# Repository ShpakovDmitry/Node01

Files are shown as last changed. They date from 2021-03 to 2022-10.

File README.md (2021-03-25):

# Node01
Node01 is wireless mesh node. This node is the basis of backbone network.

###### Network example:
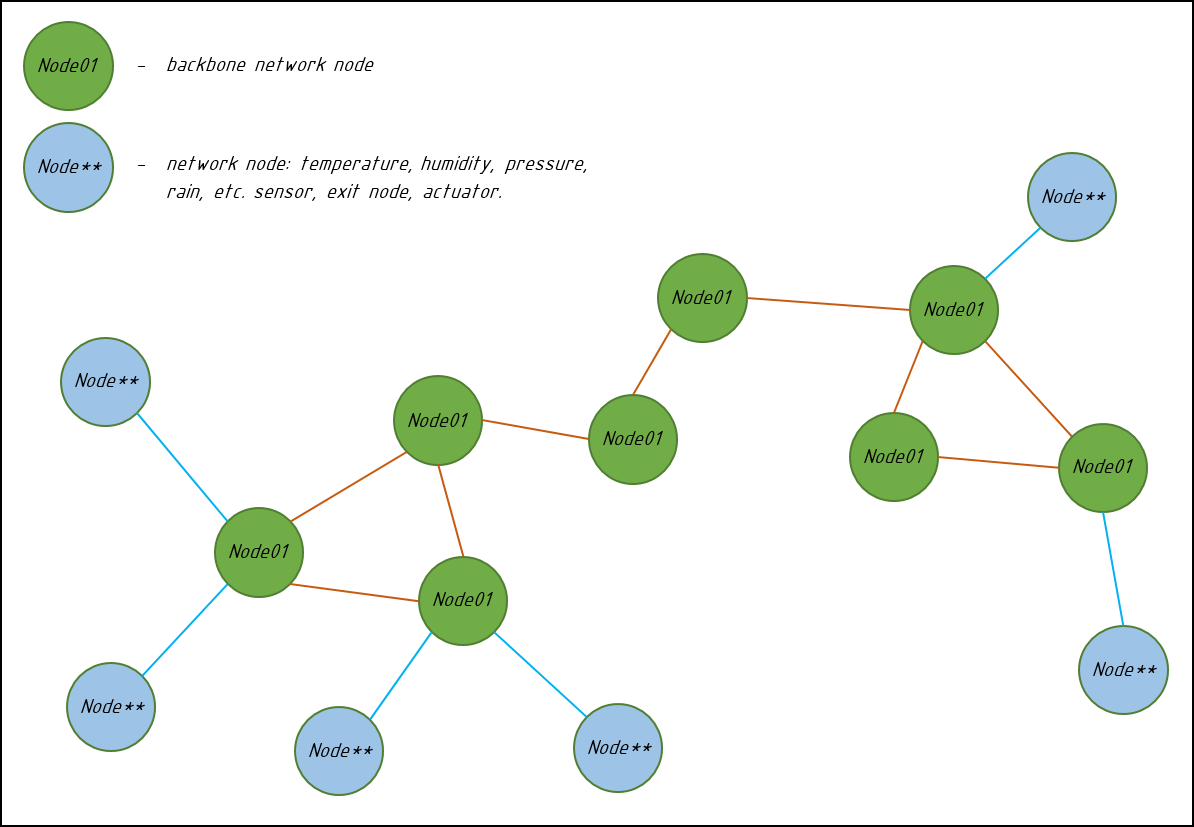
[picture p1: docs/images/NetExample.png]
netEample


###### Node01 block scheme:
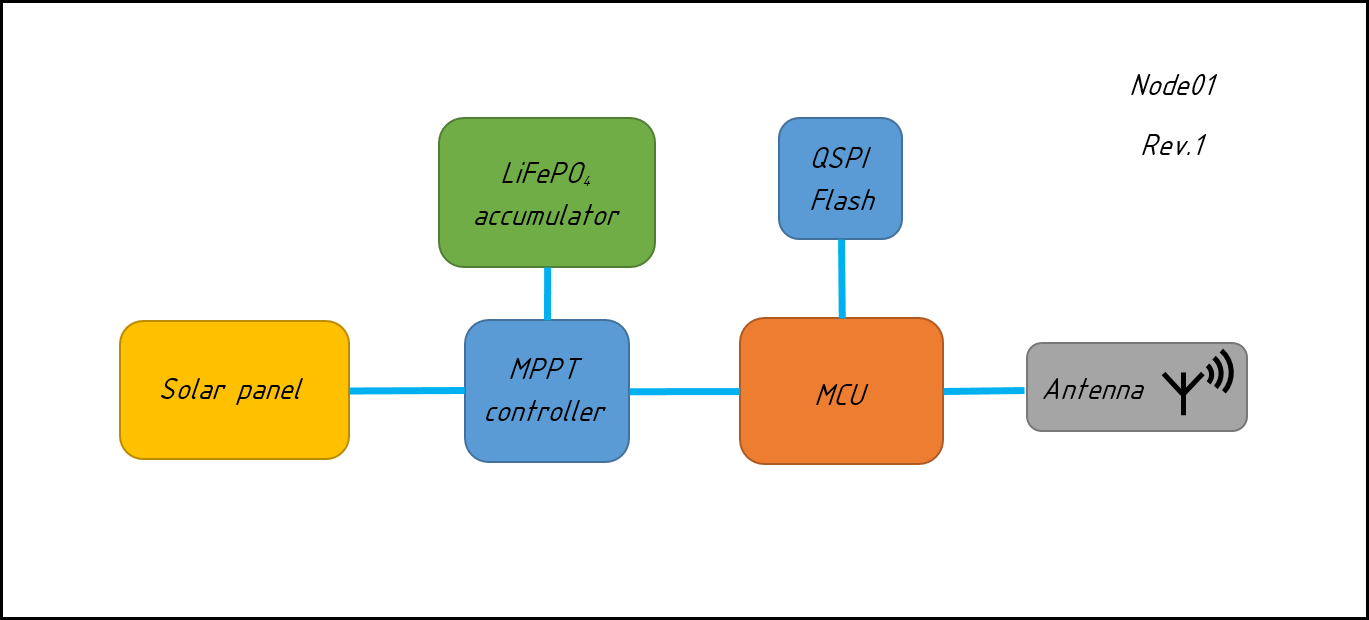
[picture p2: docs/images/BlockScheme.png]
BlockScheme


### Requirements
**Hardware**
* Based on Nordic Semiconductor IC (ex. nRF52840, ...)
* Continuous RF operation RX/TX
* Mostly static geo-position
* Autonomous power supply with a backup battery source
* Energy storage is supercap or LiFePO4(operates at low temperatures)
* Power connector for external solar panel or another energy source if available
* Switchable antenna to on-board or external SMA connector
* -40...+80 C deg outdoor temperature of operation
* minimum IP-63 protection
* Self monitor feature (integral temperature, battery lifetime monitoring)
* Flash storage IC
* UART interface
* 

**Software**
* Proprietary 2.4GHz protocol
* Operates as a router/switch
* Event based cooperative scheduler(in plans)
* Event-driven active object paradigm
* Or some of RTOS
* Modular hardware dependant part i.e. change in base board does not change
logic
of operation. Hardware are accessed throught API.
* C++ mixed with C and ASM for performance critical code sections(if possible)
* FOTA update
* Communication security: TBD !
* Minimal maintenance concept
* Self test feature
* Delay reliable communication
*

###### Power consumption analysis
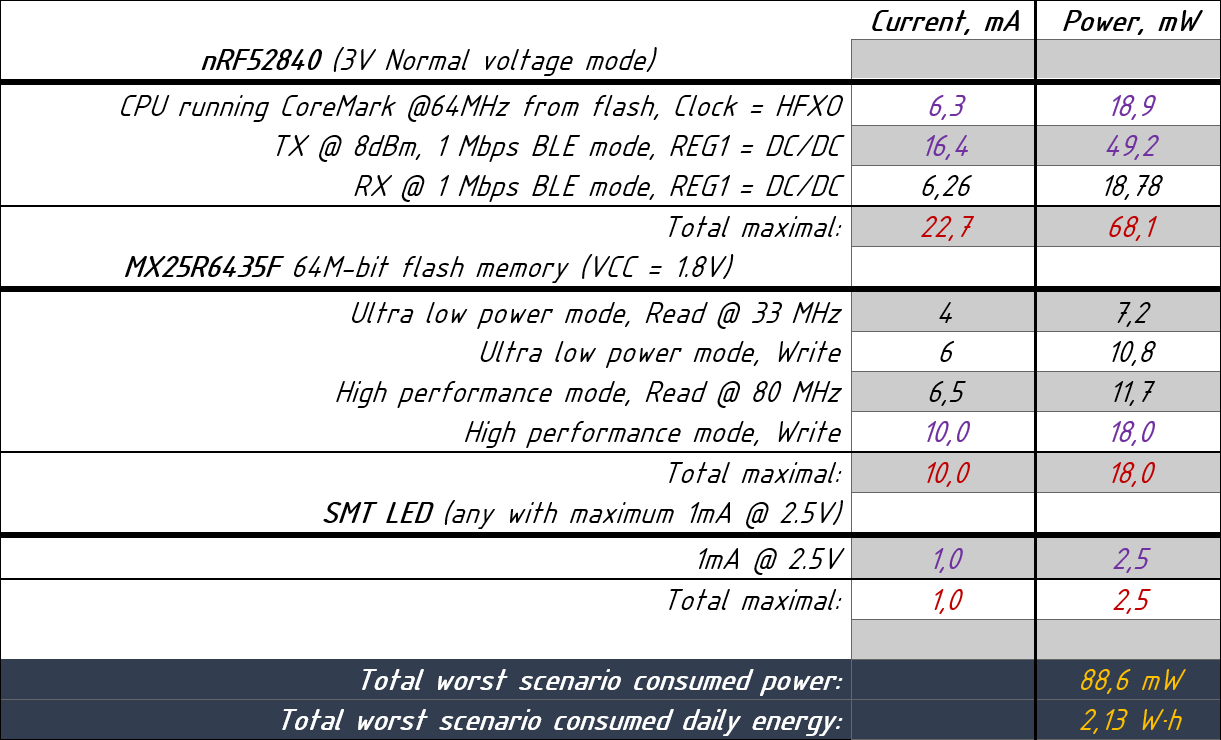
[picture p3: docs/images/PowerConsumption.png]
PowerConsumption

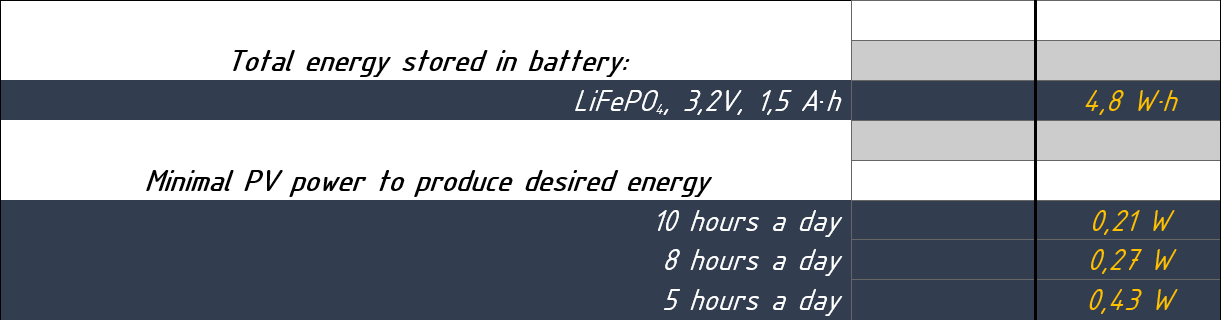
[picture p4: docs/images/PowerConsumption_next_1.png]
EnergyStored


###  Progress checklist
**Documentation**
- [x] Technical specifications added.
- [x] Power consumption analysis.
- [ ] Description.
- [ ] Hardware.
- [ ] Source.

**Hardware**
- [ ] Schematics designed.
- [ ] Simulations.
- [ ] PCB routed.
- [ ] Simulations.
- [ ] Rev. 1 manufactured.
- [ ] Rev. 1 tested.
- [ ] Changes to Rev. 1 made.
- [ ] Rev. 2 manufactured.
- [ ] Rev. 2 tested.
- [ ] Test passed.

**Software**
- [ ] Coding style guidleines added.
- [ ] Project guidlines added.
- [ ] Project organized.
- [ ] Build system created.
- [ ] Unit test system created.
- [ ] ... TBA
- [ ] MVP.
- [ ] Release of v.1.0.0

ProjectLogs

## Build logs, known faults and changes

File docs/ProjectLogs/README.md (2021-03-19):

# Project logs
> The purpose of this is to write decisions and changes made to project.

Put:
* current commit hash i.e. at the begining of discussion.
* Date.
* Reporter name.
* Problem description.

---

## Table of contents

1. [Power consumption analysis](#power-consumption-analysis)
1. [MPPT controller](#mppt-controller)
1. [Backup battery](#backup-battery)
1. [Energy sources](#energy-sources)
1. [Energy accumulator](#energy-accumulator)

##### Power consumption analysis.
```
       Number: 1
Project state: 4f51f26244daa80a04ce5664aafaebc53eb92157
         Date: 18/03/2021
     Reporter: Dmitry
      Problem: Too high power consumption, too high energy storage, too high
               PV power.
```
According to current setup,

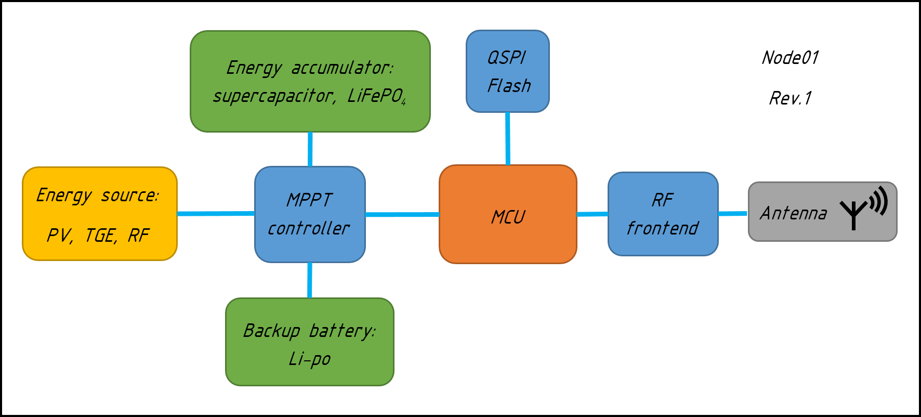
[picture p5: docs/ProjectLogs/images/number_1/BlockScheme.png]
BlockScheme


power consumption analysis showed that worst
scenario daily consumed energy is `10.6 W*h`. Excluding system efficiency out
of calculation. Energy transfer - store - transfer efficiency could be ~80 %.

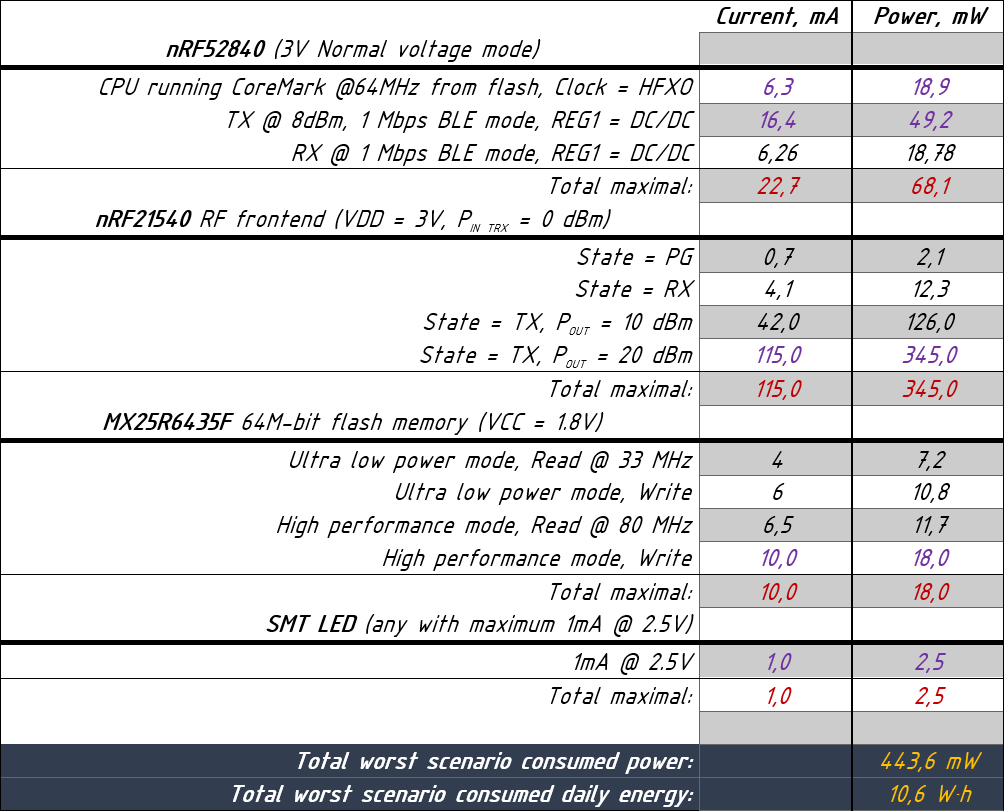
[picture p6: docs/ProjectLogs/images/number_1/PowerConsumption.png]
PowerConsumption


Which leads to LiFePO4 battery with `3.3 A*h` minimal capacity. Thus, to fully
charge up this battery in most optimistic scenario, 10 hour sunny day, `1.06 W`
PV panel is needed. Or `2.12 W` PV panel in 5 hour sunny day.

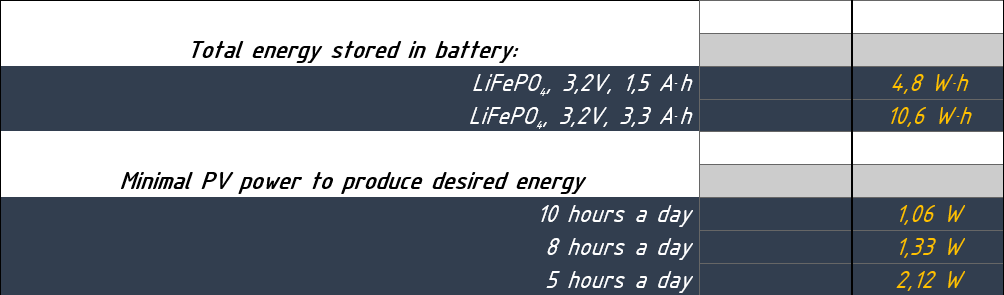
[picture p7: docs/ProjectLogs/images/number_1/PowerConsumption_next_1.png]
EnergyStored


```
Solution: Exclude RF frontend. This will lower worst scenario power consumption
          by `345 mW`.
```

##### MPPT controller.
```
       Number: 2
Project state: 83ee388a7370879099274ff98fa68130488713f3
         Date: 18/03/2021
     Reporter: Dmitry
      Problem: Is AEM10941 MPPT controller suitable for current setup?
```
If we assume that there is minimum 5 hour of sun a day then `0.43 W` PV is
needed. If accept that energy converter is 80% efficient, then we need
`0.54 W` PV. According to `AEM10941` [datasheet](../datasheet/DS_AEM10941.pdf)
maximal harvesting power is `550 mW` at `5 V` input voltage.

```
Solution: AEM10941 is suitable for this setup.
```

###### Backup battery.
```
       Number: 3
Project state: bc0d5789db9773c0944a8ec2a8e91152fdf4df60
         Date: 19/03/2021
     Reporter: Dmitry
      Problem: Is backup battery actually required?
```

According to current setup,

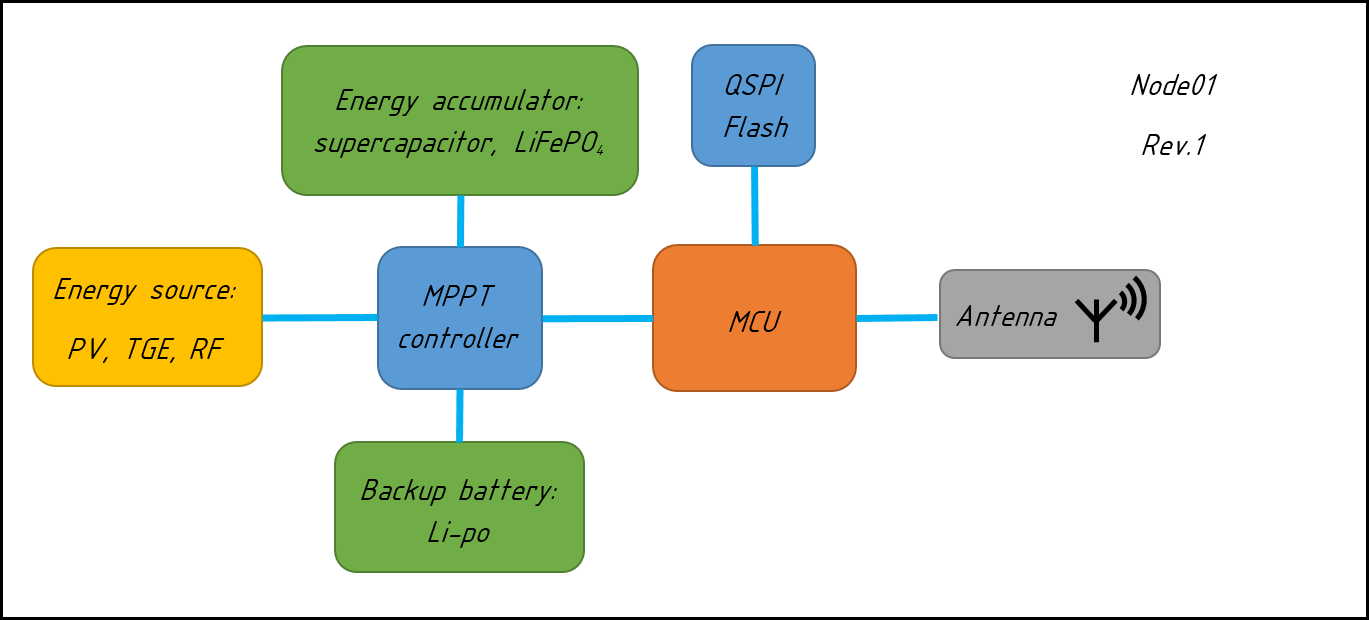
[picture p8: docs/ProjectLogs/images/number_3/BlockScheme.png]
BlockScheme


High capacity Li-po backup battery is used for periods of time when there is a
lack of harvested energy. This high capacity battery is precharged at install
in to device, and is not being charged during energy harvesting. Because if it
would be charged, then there is no meaning of two batteries, we could simply
increase capacity of rechargable one. Also use of this battery means that there
will be time when this battery should be replaced with charged one in order to
device successfully operates, as it will rely on existance of such backup
battery. So, using this battery means that we should track stored energy in
this battery and replace when it is empty. This leads to additional regular
maintenance of end device. This is in a contradiction with
_minimal maintenance concept_ described in device requirements.
```
Solution: exclude backup Li-po battery from design.
```

###### Energy sources.
```
       Number: 4
Project state: 1ef03a4303f460e012a083986df158970c159b4b
         Date: 19/03/2021
     Reporter: Dmitry
      Problem: What kind of energy sources actually will fit to the design?
```

According to current setup,

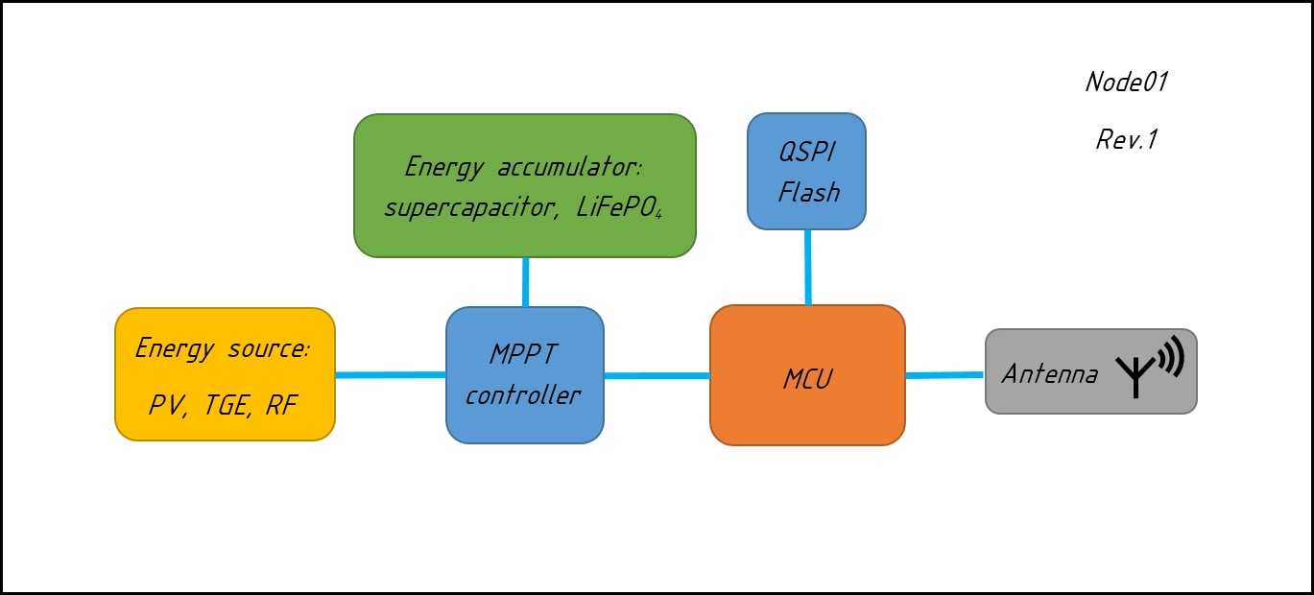
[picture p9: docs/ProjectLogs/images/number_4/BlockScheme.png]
BlockScheme


Energy sources used are photovoltaics(PV), thermo-electric generator(TEG),
radio-frequency energy(RF). Here we assume low cost, small size device is
desired.

| Energy source | Pros | Cons |
|:---:|:---:|:---:|
| RF | 24/7 operation | need nearby source, size  |
| TEG | 24/7 operation | good cooling system, size |
| PV | cheap, scalability | sunlight required, |

RF energy source will increase size of the device, also it will suffer
from RF energy source. TEG requires good cooling system and so will increase
size of the device. PV will increase size of the device, will operate only when
sunlight exists. Best candidate for this setup is PV as is cheap, easy scalable.
```
Solution: exlude RF, TEG energy sources variant from design. Leave only PV.
```

###### Energy accumulator.
```
       Number: 5
Project state: 4d961711aa97c4df6a963df5bf95f50167170b24
         Date: 19/03/2021
     Reporter: Dmitry
      Problem: What kind of energy accumulator will fit the best to the design?
```

Two candidates for current design:

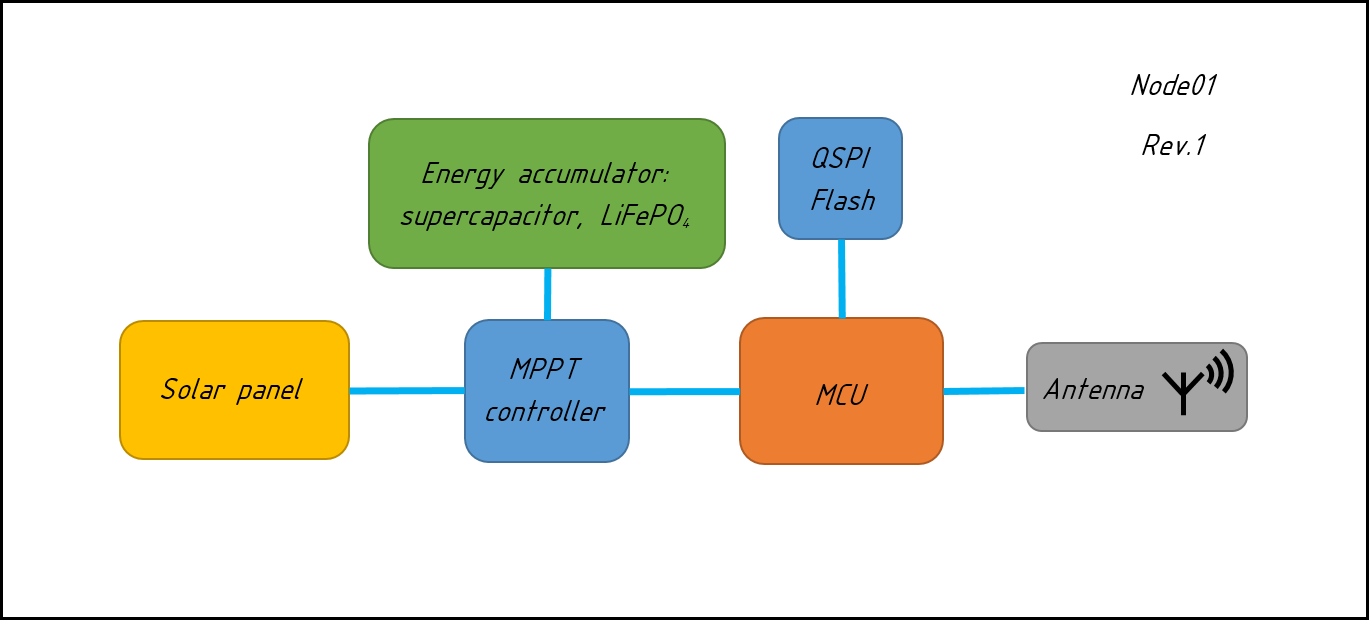
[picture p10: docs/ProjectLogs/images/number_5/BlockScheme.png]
BlockScheme


are supercapacitor and LiFePO4 battery.

| Energy accumulator | supercapacitor | LiFePO4 |
|:---:|:---:|:---:|
| Temp. range, C | -40...+125 | -40...+85 |
| Recharge cycles | 100k...1000k | 2k...10k |
| Specific en., Wh/kg| 1,5...3,9 | 90...160 |
| Specific pow., W/g | 2...10 | 0.3...1.5 |
| Self-discharge | weeks | months |
| Efficiency, % | 95 | 90 |
| Working life, y | 5...10 | 3...5 |

Both accumulators can be used in desired temperature range. LiFePO4 batteries
are with extended operation temperature range compared with Li-ion batteries.
However supercapacitors have higher recharge cycle amount, which means lower
maintenance. Looking at specific energy of accumulator here LiFePO4 battery is
out of concurence. This however means smaller device size. But supercapacitors
have higher specific power. But this criteria is not so meaningfuls as device
it self is low power. LiFePO4 self-discharge parameter is definitelly a win,
because any energy leakage means higher battery capacity or higher PV power.
Efficienty of both are comparable. And five years working life is acceptable.
So, for current design will stay at LiFePO4 batteries.
```
Solution: Use LIFePO4 battery.
```

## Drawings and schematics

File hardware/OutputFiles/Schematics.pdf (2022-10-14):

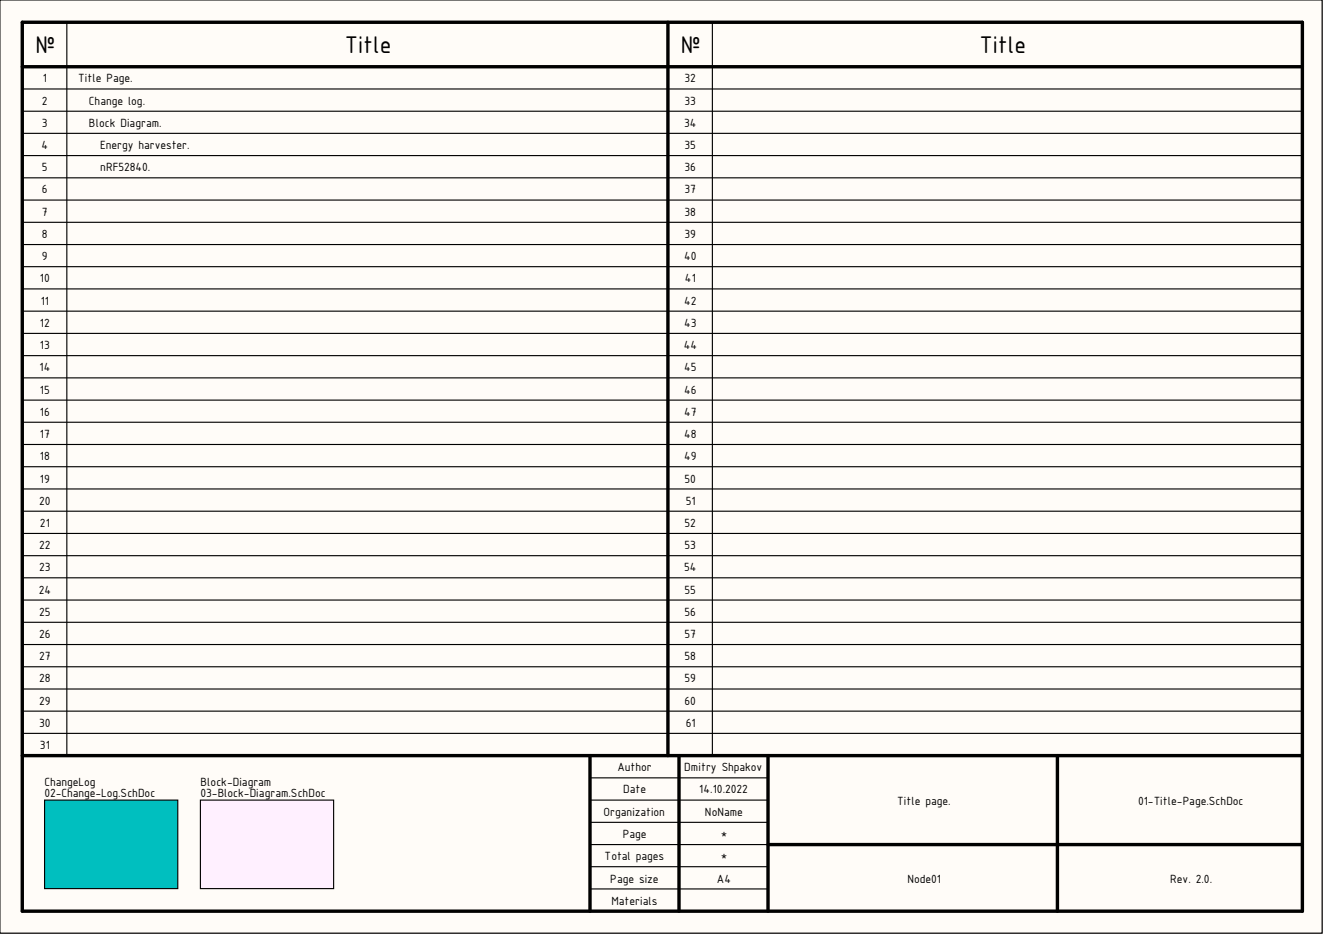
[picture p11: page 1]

№ | Title | № | Title

1 | Title Page. | 32

2 | Change log. | 33

3 | Block Diagram. | 34

4 | Energy harvester. | 35

5 | nRF52840. | 36

ChangeLog Block-Diagram 02-Change-Log.SchDoc 03-Block-Diagram.SchDoc | Author | Dmitry Shpakov | Title page. | 01-Title-Page.SchDoc

Date | 14.10.2022

Organization | NoName

Page | *

Total pages | * | Node01 | Rev. 2.0.

Page size | A4

Materials

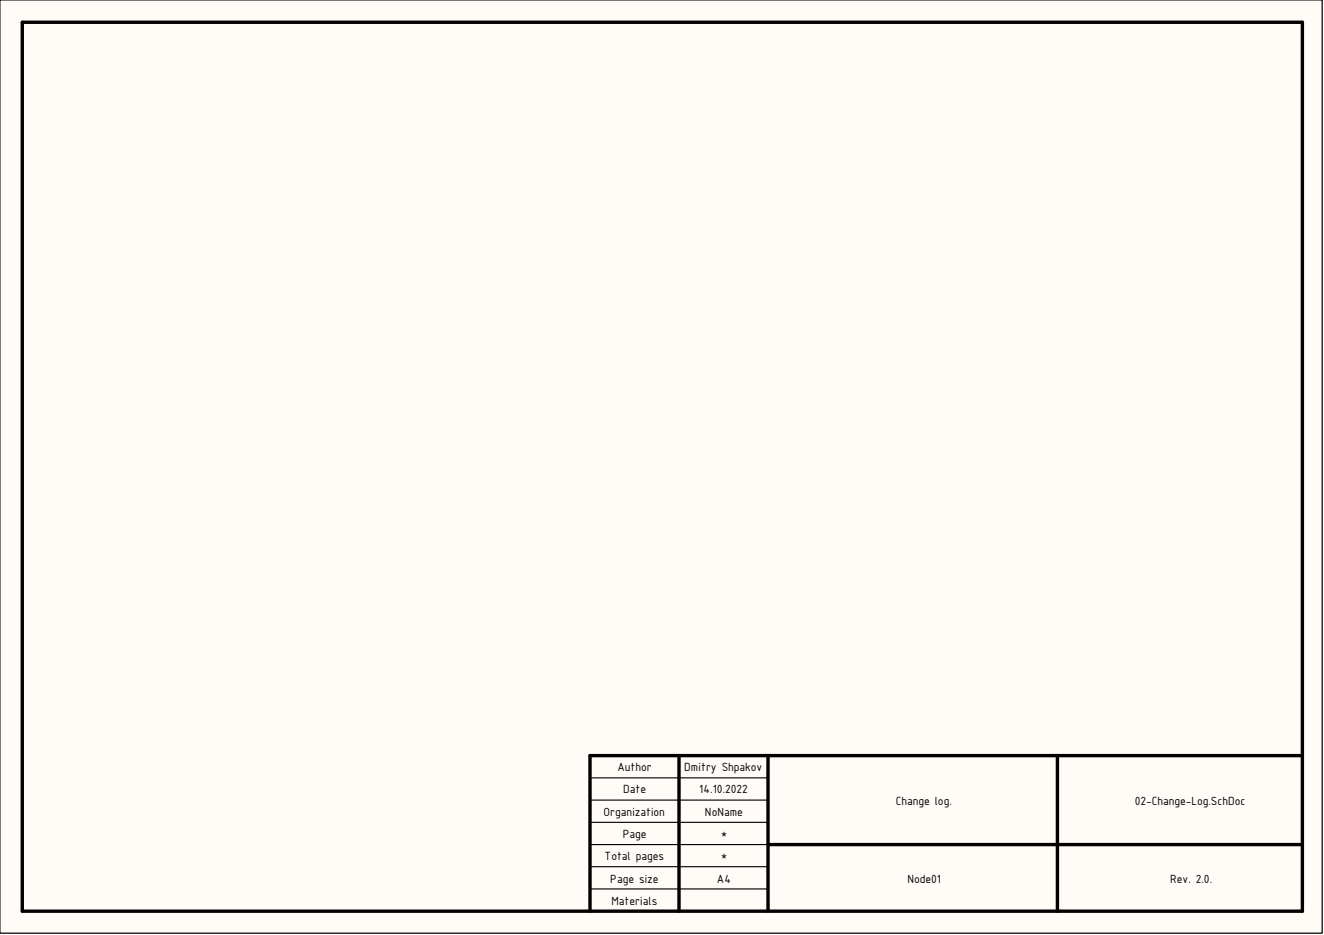
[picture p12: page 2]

Author | Dmitry Shpakov | Change log. | 02-Change-Log.SchDoc

Date | 14.10.2022

Organization | NoName

Page | *

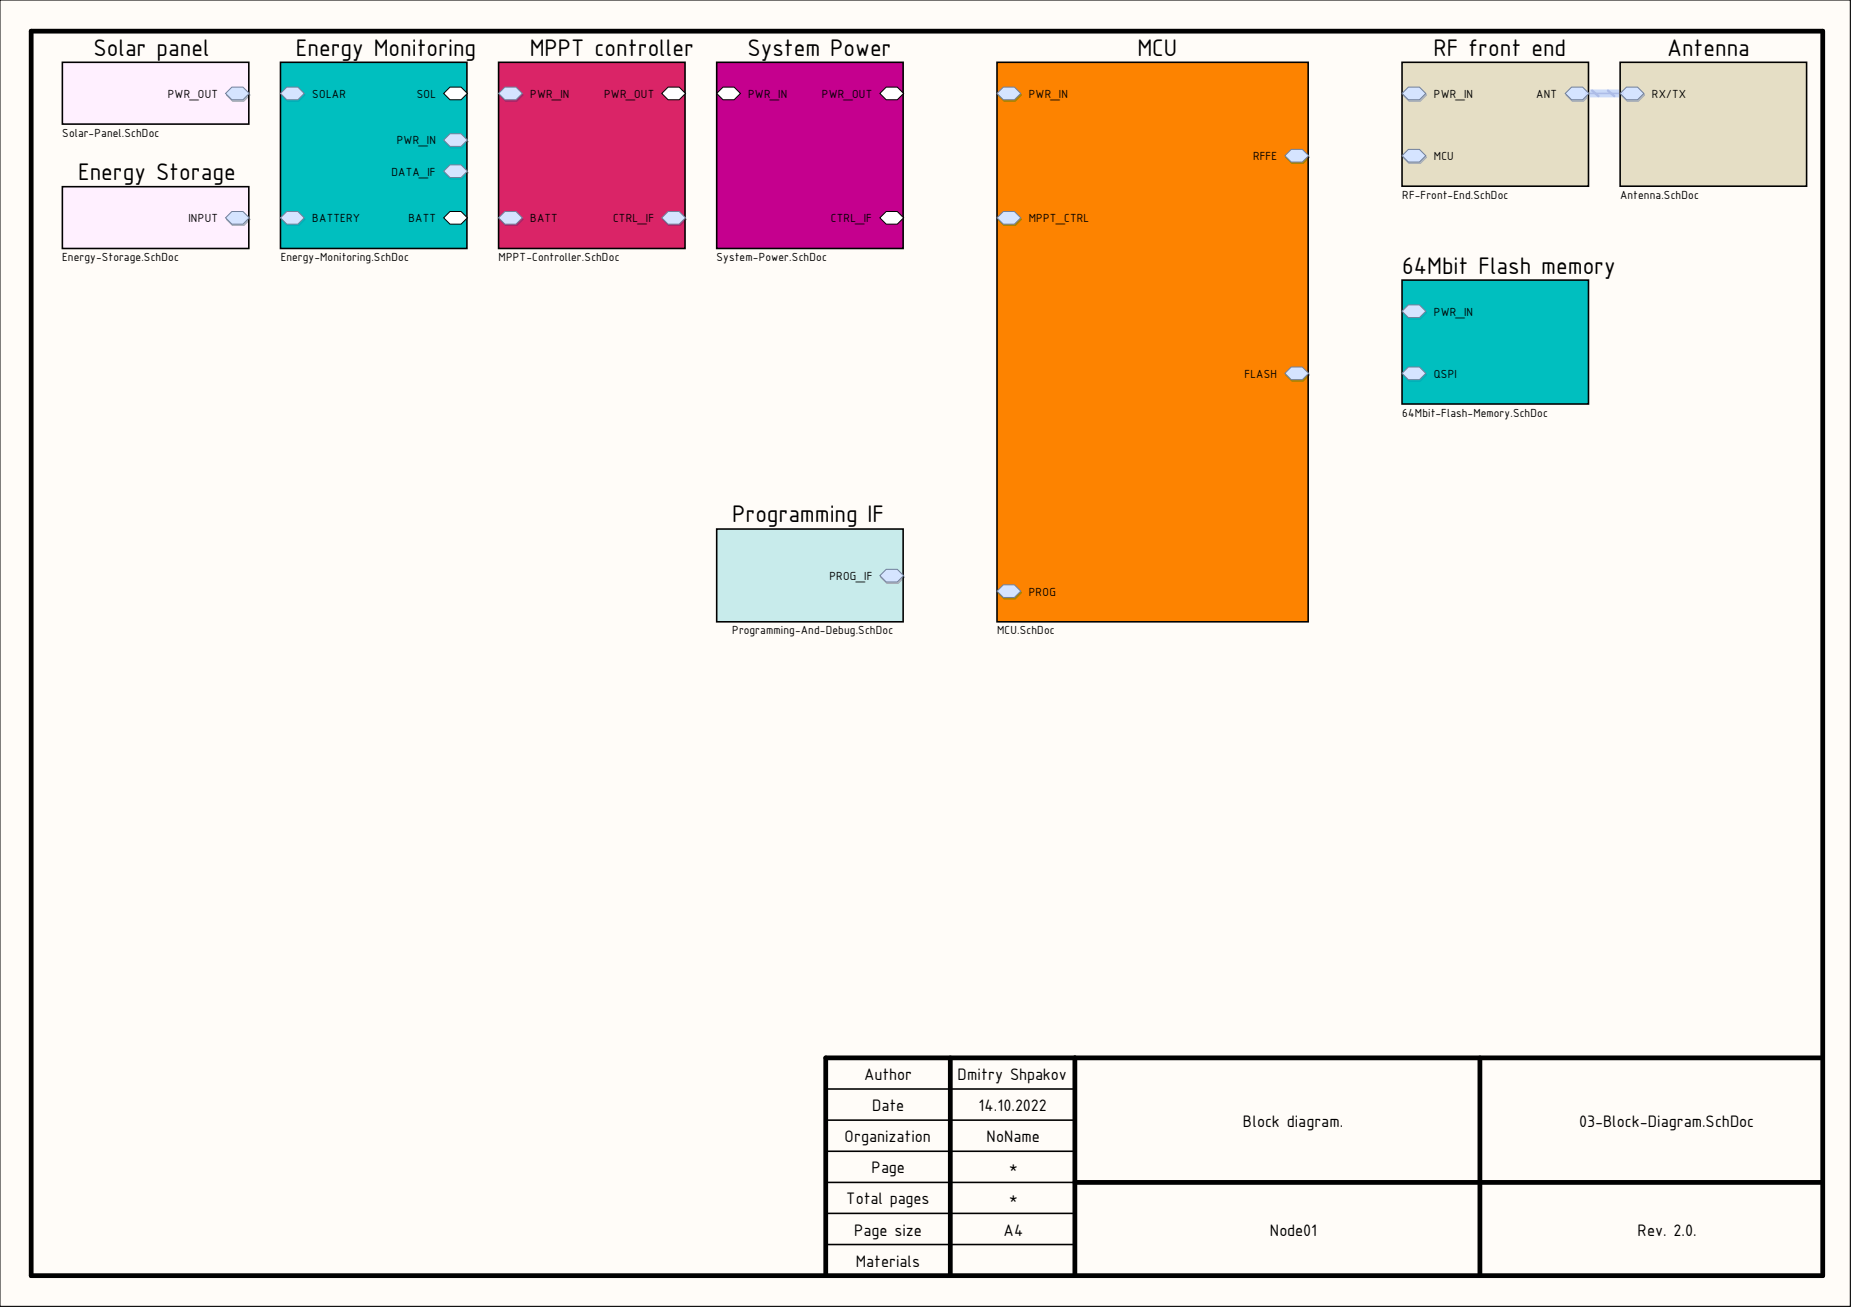
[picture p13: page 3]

RF-Front-End.SchDoc

Programming-And-Debug.SchDoc

Author | Dmitry Shpakov | Block diagram. | 03-Block-Diagram.SchDoc

Date | 14.10.2022

Organization | NoName

Page | *

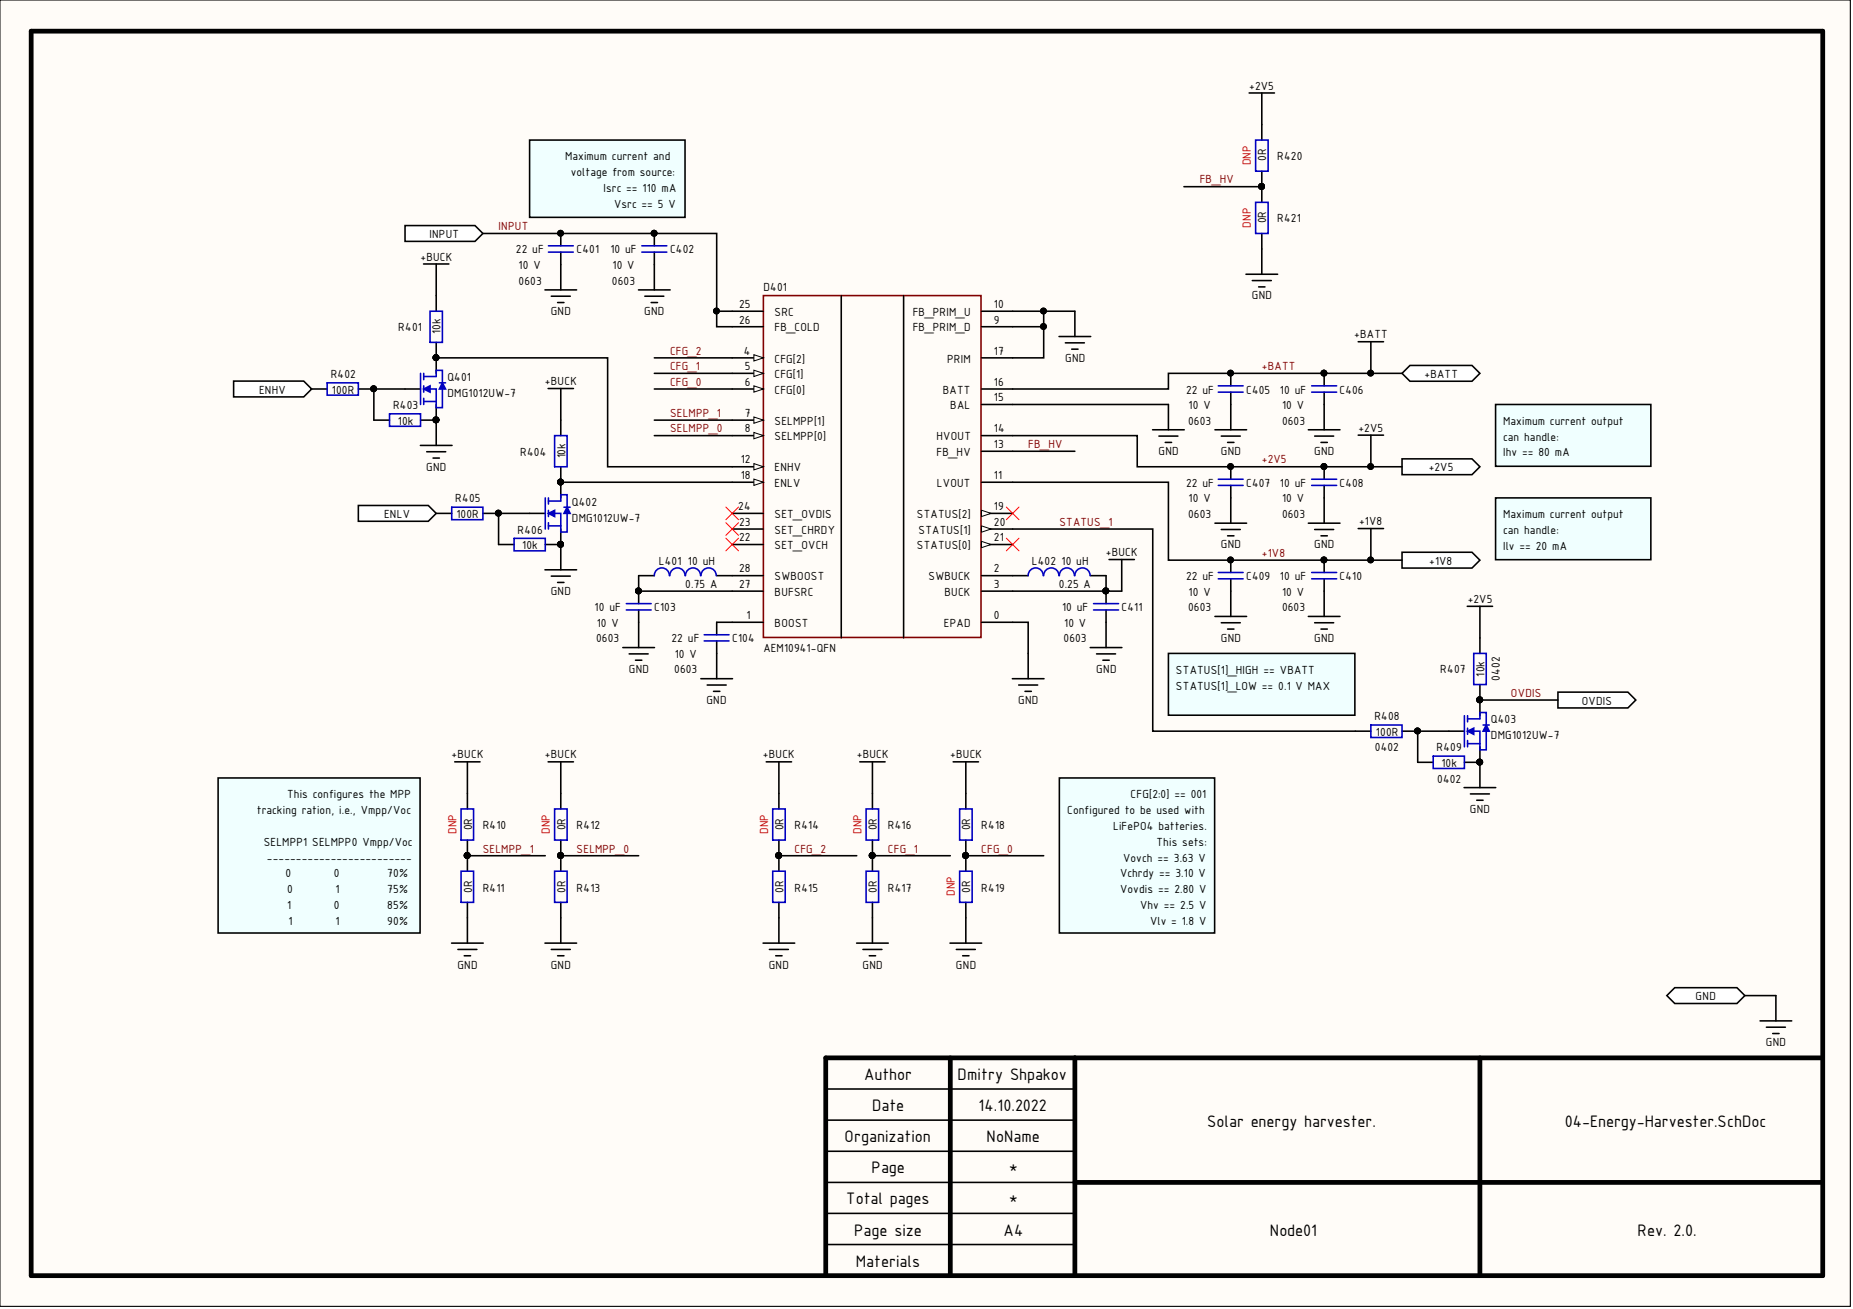
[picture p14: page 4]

This configures the MPP
tracking ration, i.e., Vmpp/Voc

Configured to be used with

Author | Dmitry Shpakov | Solar energy harvester. | 04-Energy-Harvester.SchDoc

Date | 14.10.2022

Organization | NoName

Page | *

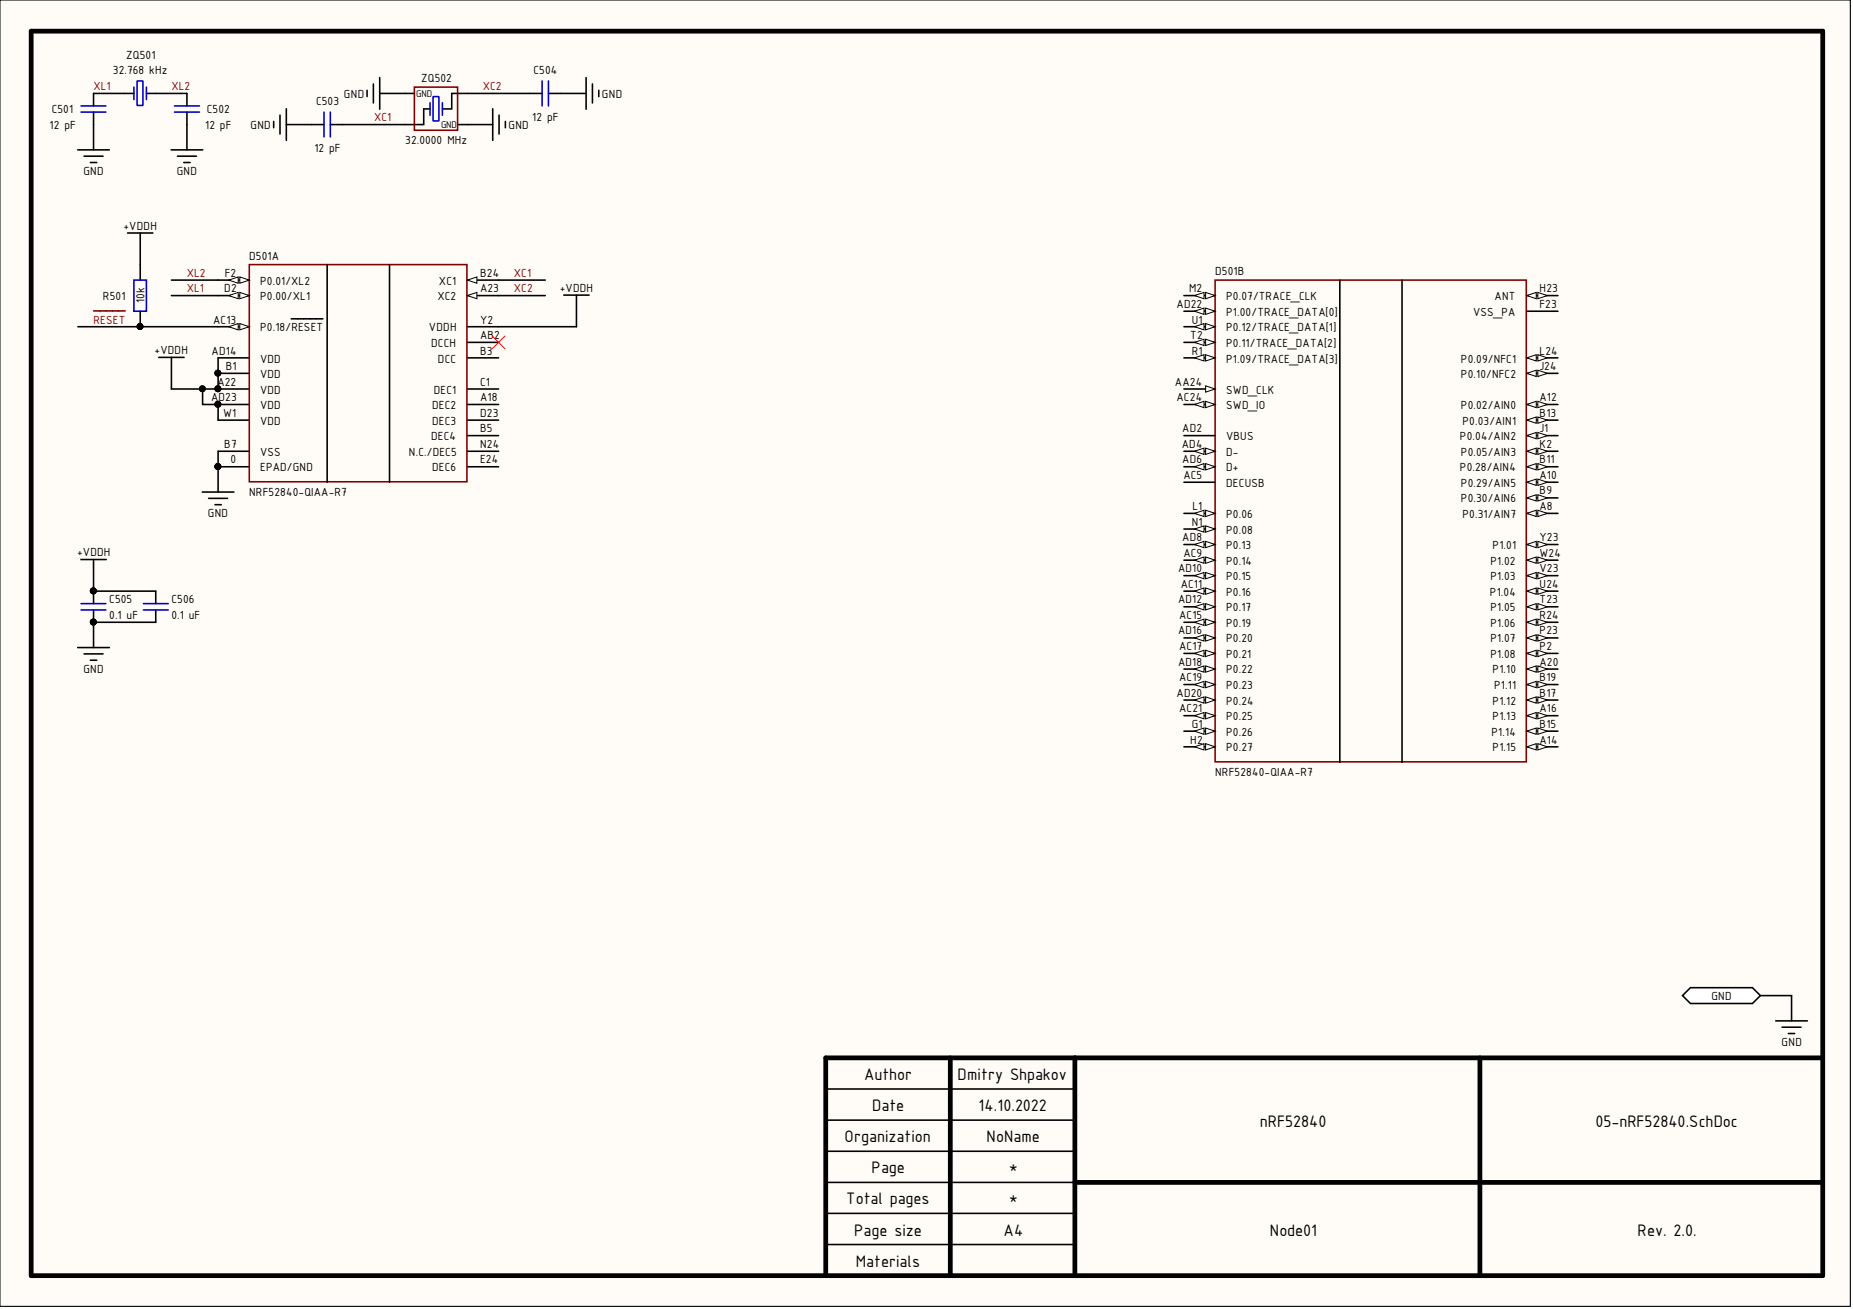
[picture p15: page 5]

Author | Dmitry Shpakov | nRF52840 | 05-nRF52840.SchDoc

Date | 14.10.2022

Organization | NoName

Page | *

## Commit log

2021-02-25 +) hardware::schematic > initial add
    [MainDesign.SchDoc, Node01.PrjPcb, Page1.SchDoc]
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2021-03-19 +)lib: AEM10941 added
    [MainDesign.SchDoc, Page1.SchDoc]
2021-03-20 +)schematic: passives added
    [Page1.SchDoc]
2021-03-20 +)schematic: added MPP ratio selection
    [Page1.SchDoc]
2021-03-20 *)schematic: minor changes
    [Page1.SchDoc]
2021-03-23 +)schematic: 18650 battery holder added
    [Page1.SchDoc]
2021-03-23 +)schematic: added holder info
    [Node01.PrjPcb, Page1.SchDoc]
2021-03-23 +)schematic: added status output
    [Page1.SchDoc]
2021-03-23 *)schematic: renamed
    [01_MPPT_controller.SchDoc, Node01.PrjPcb, Page1.SchDoc]
2021-03-23 -)schematic: removed obsolete file
    [Page1.SchDoc]
2021-03-24 +)lib: nRF52840 component created
    [01_MPPT_controller.SchDoc, 02_nRF52840.SchDoc, Node01.PrjPcb]
2021-03-25 +)schematic: LF crystall created
    [02_nRF52840.SchDoc]
2021-03-25 +)schematic: HF crystall added
    [02_nRF52840.SchDoc, Node01.PrjPcb]
2021-03-26 +)schematics: power and clock done
    [01_MPPT_controller.SchDoc, 02_nRF52840.SchDoc, 02_nRF52840_power_clock.SchDoc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]
2021-03-26 +)schematic: RESET pull up added
    [02_nRF52840_power_clock.SchDoc]
2021-03-26 +)schematics: preliminary RF part designed
    [01_MPPT_controller.SchDoc, 02_nRF52840_power_clock.SchDoc, 03_nRF52840_RF.SchDoc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]
2021-03-26 +)schematic: NFC and USB part designed. Unused.
    [03_nRF52840_RF.SchDoc, 04_nRF52840_NFC_USB.SchDoc, Node01.PrjPcb]
2021-04-03 +)schematic: SWD interface added
    [01_MPPT_controller.SchDoc, 02_nRF52840_power_clock.SchDoc, 03_nRF52840_RF.SchDoc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]
2021-04-04 +)schematic: program interface added
    [02_nRF52840_power_clock.SchDoc, 05_nRF52840_Debug_and_Trace.SchDoc, Node01.PrjPcb]
2021-04-05 +)schematic: PV and BATT volatage measurement added
    [01_MPPT_controller.SchDoc, 02_nRF52840_power_clock.SchDoc, 05_nRF52840_Debug_and_Trace.SchDoc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]
2021-04-05 +)schematic: UART added
    [06_nRF52840_Analog.SchDoc, 07_nRF52840_Digital.SchDoc, Node01.PrjPcb]
2021-04-10 +)schematic: 64Mbit QSPI NOR Flash added
    [07_nRF52840_Digital.SchDoc]
2021-04-11 +)schematic: main design added
    [00_Main_Design.SchDoc, 01_MPPT_controller.SchDoc, 02_nRF52840_power_clock.SchDoc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]
2021-04-11 +)Documentation: output job file created
    [00_Main_Design.SchDoc, 01_MPPT_controller.SchDoc, 02_nRF52840_power_clock.SchDoc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]
2021-04-11 +)schematic: main design sheet changed
    [00_Main_Design.SchDoc, 01_MPPT_controller.SchDoc, 02_nRF52840_power_clock.SchDoc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]
2021-04-12 +)PCB: part of MPPT controller routed
    [01_MPPT_controller.SchDoc, 02_nRF52840_power_clock.SchDoc, 10_Program_and_Debug_interface.SchDoc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]
2021-04-13 +)PCB: MPPT controller routed
    [01_MPPT_controller.SchDoc, 03_nRF52840_RF.SchDoc, PCB.PcbDoc]
2021-04-13 +)PCB: nRF52840:clock route started
    [PCB.PcbDoc]
2021-04-14 *)PCB: small changes
    [02_nRF52840_power_clock.SchDoc, PCB.PcbDoc]
2021-04-14 -)schematic: no need for external reset pull-up resistor
    [02_nRF52840_power_clock.SchDoc, Node01.PrjPcb]
2021-04-14 +)PCB: power part prerouted
    [02_nRF52840_power_clock.SchDoc, 03_nRF52840_RF.SchDoc, 06_nRF52840_Analog.SchDoc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]
2021-04-19 +)PCB: further routing
    [10_Program_and_Debug_interface.SchDoc, PCB.PcbDoc]
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2021-05-12 -)schematic: removed external rf connector
    [03_nRF52840_RF.SchDoc]
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2022-08-11 *) schematic:MPPT: removed obsolete ports
    [01_MPPT_controller.SchDoc]
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2022-08-12 massive cleanout before version 2
    [00_Main_Design.SchDoc, 01_MPPT_controller.SchDoc, 02_nRF52840_power_clock.SchDoc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]
2022-08-12 empty project template created
    [00-Title-Page.SchDoc, 01-Block-Diagram.SchDoc, Node01.PrjPCB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]
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2022-08-12 Added schematic doc parameters
    [00-Title-Page.SchDoc, 01-Block-Diagram.SchDoc]
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2022-08-14 added jumper resistor to project lib
    [Node01.PrjPCB]
2022-08-14 added inductor to lib
    [Node01.PrjPCB]
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2022-08-15 created enrgy harvester sheet and updated paramters
    [00-Title-Page.SchDoc, 01-Change-Log.SchDoc, 02-Block-Diagram.SchDoc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]
2022-08-15 added entry to TOF
    [00-Title-Page.SchDoc]
2022-08-15 addedharvester IC to schematics
    [04-Energy-Harvester.SchDoc]
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2022-08-16 added 0402 resistor footprint
    [04-Energy-Harvester.SchDoc, Node01.PrjPCB]
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2022-08-16 added 0603 capacitor footprint
    [04-Energy-Harvester.SchDoc, Node01.PrjPCB]
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2022-08-18 updated energy harvester schematics
    [04-Energy-Harvester.SchDoc, Node01.PrjPCB]
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2022-08-22 updated sheet symbol ports
    [03-Block-Diagram.SchDoc]
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2022-08-22 added ovdis level translator
    [03-Block-Diagram.SchDoc, 04-Energy-Harvester.SchDoc]
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2022-08-23 set no warning on pin driving source
    [Node01.PrjPCB]
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2022-08-23 added 18650 battery holder
    [Node01.PrjPCB]
2022-08-23 added battery to schematics
    [03-Block-Diagram.SchDoc]
2022-08-23 initial add of nRF52840 schematics
    [03-Block-Diagram.SchDoc, 05-nRF52840.SchDoc, Node01.PrjPCB]
2022-08-23 added 32.768 kHz oscillator
    [05-nRF52840.SchDoc, Node01.PrjPCB]
2022-08-23 added LF oscillator to schematics
    [05-nRF52840.SchDoc]
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2022-08-24 LF oscillator added
    [05-nRF52840.SchDoc]
2022-08-24 added HF oscillator
    [05-nRF52840.SchDoc]
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2022-08-24 added several decoupling capacitors
    [05-nRF52840.SchDoc]
2022-09-15 schematics pdf output job file created
    [Node01.PrjPCB]
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2022-10-12 added QSPI harness definition
    [Node01.PrjPCB]
2022-10-14 updated high level schematics
    [03-Block-Diagram.SchDoc]
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
